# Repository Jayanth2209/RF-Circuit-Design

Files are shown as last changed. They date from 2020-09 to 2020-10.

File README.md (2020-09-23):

# RF Circuit Design
#### [Link to the Video](https://youtu.be/TnRn3Kn_aXg)         

### Five Rules: 
#### 1) Use 4 Layers:      
* Top (RF and Signals)          
* GND just below 1                 
* VCC above the bottom (15 on Eagle)           
* Bottom (Signals)             

* Use a consistent stack-up            
* Dedicate entire inner layers to unbroken power supply planes           
* Keep RF Signals on Top     

##### 4-Layer Board stackup:   
The 4 layer board stackup is as follows:      
* 1 mil solder resist      
* 1 oz Cu (1.4 mil)    
* 6.7 mil prepreg     
* 0.5 oz Cu (0.7 mil)   
* 47 mil Core     
* 0.5 oz Cu (0.7 mil)           
* 6.7 mil prepreg        
* 1 oz Cu (1.4 mil)         
* 1 mil solder resist         

[Setting up Multi-layer on Eagle](https://youtu.be/0sVUkjXbqrM)            

#### 2) Choose Integrated components:     
Try to choose and use the most integrated components - RF ICs, Baluns, Filters, etc.     
Examples of RF ICs - CC2650, CC1310, AT86RF215, nRF24L01P(+) ans so many more integrated RF ICs are available...        

#### 3) 50 Ohms everywhere:     
Try to match everything to 50 ohms. If a component is not 50 ohms I/O or whatever, convert it to 50 ohms.     
How? - Refer to it's Datasheet (Matching/Application Circuit)    

* Follow Manufacturer Recommendations (for matching)  -------------  **(4)**      

##### Note: For matching the RF traces on the Top layer of the circuit board to 50 Ohms, they have to be 12 mils wide (Considering the 4 layer board stackup specifications as mentioned above). So, on Eagle, Set - Trace width = 12 mils, Trace thickness = 1.4 mils             

After making your circuit, with all the above rules in mind:       
* Route RF first  --------------  **(5)**    
* Keep RF traces short and direct     
* Keep other signals away from RF (keep buffer zones next to RF traces, try to route other signals considerable away from RF signals)

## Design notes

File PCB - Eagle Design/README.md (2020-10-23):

# PCB        
A PCB has been designed on Eagle with the following components:           
[Reference Schematic]()          

* RF Transceiver:      
CC1121 - Texas Instruments        
[Datasheet - CC1121](https://www.ti.com/lit/ds/swrs111f/swrs111f.pdf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)       

* Antenna:     
ANT-916-CW-RCL-CCC      
[Antenna Datasheet]()       

* Other Components(Crystal Oscillator, Capacitors, Resistors and Inductors)       
[Components List]()      

* RF Module with Type-C USB Connector: Designed using Eagle       
[RF Module 1]()        
This module can be independently powered via a type-C USB connector or it can also be interfaced with an MCU(includes VCC, GND, GPIOs and pins corresponding to SPI Interfacing of the module)     

* RF Module without Type-C connector: Designed using Eagle      
[RF Module 2]()       
Only for interfacing with MCUs       
 
### PCB Design Guidelines:
Refer to these for important things to note while designing a PCB:     
[General guidelines for desiging an aesthetically pleasing PCB]()             
[RF PCB Design - A few things to note]()          

### Comparing the various types of Commercially available antennas:         

### Increasing the range of an RF-Module and theoretical Range estimations:           

### Calculating the range of the above designed PCB (CC1121 RF Transceiver):

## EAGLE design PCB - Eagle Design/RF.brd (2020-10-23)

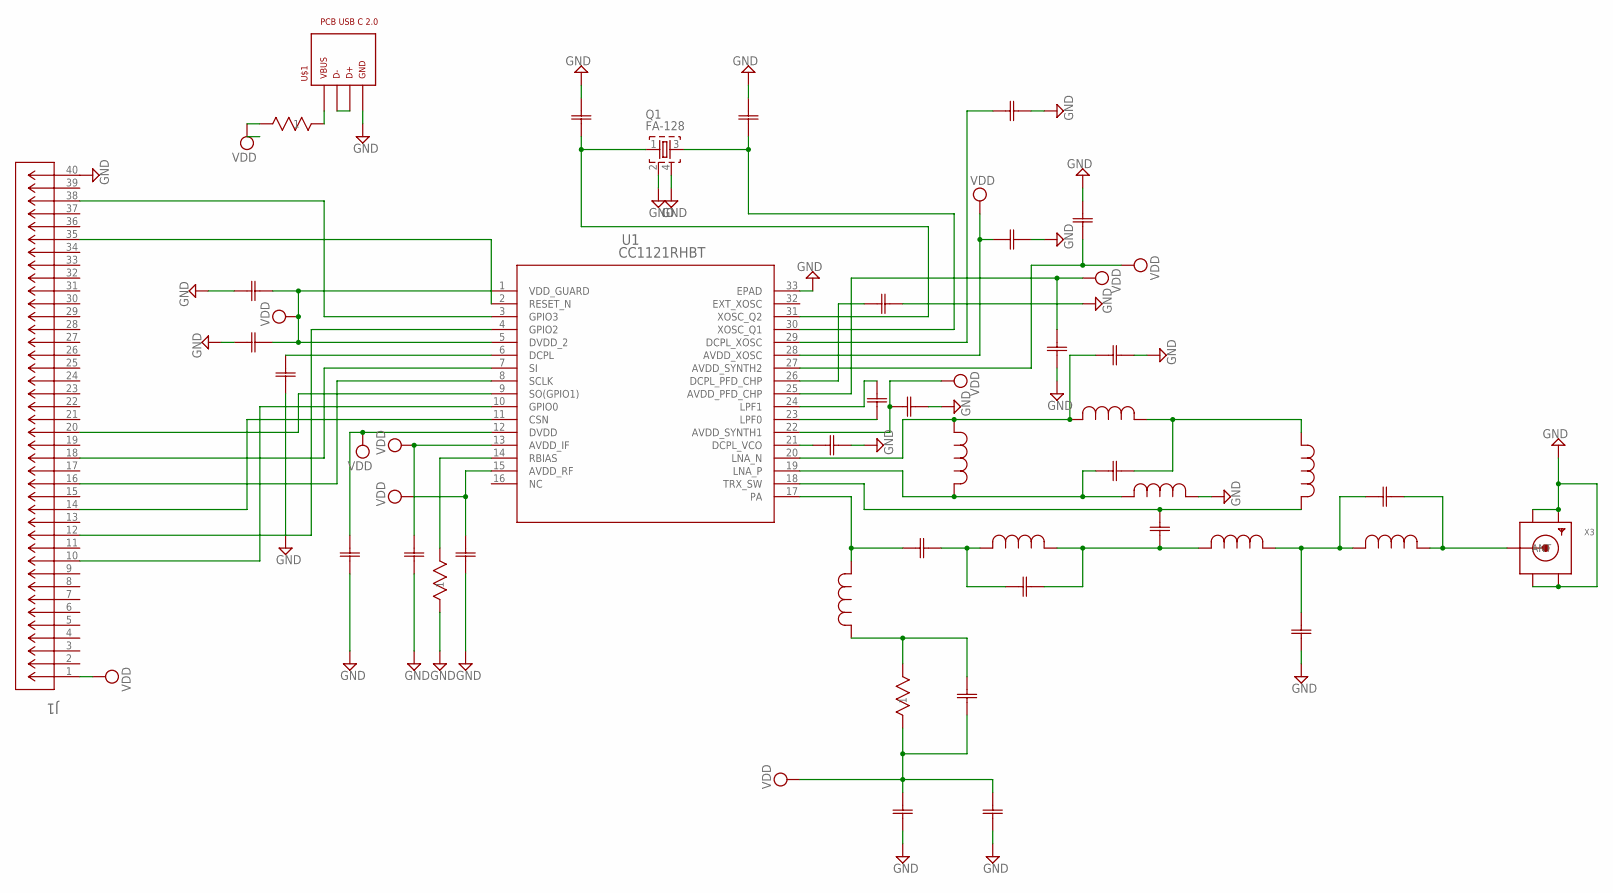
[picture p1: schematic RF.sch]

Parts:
C1, C9: 220nF; G-155_MUR
C2, C6, C7, C8, C20, C21, C22, C23, C26: 47nF; G-155_MUR
C3, C24, C25: 15pF; G-155_MUR
C4: 1pF; G-155_MUR
C5: 2.2pF; G-155_MUR
C10: 33pF; G-155_MUR
C11, C12: 10pF; G-155_MUR
C13: 3pF; G-155_MUR
C14: GRM155R71A104KA01D; G-155_MUR
C15, C16: 3.3pF; G-155_MUR
C17, C18: 10nF; G-155_MUR
C19: 1.8nF; G-155_MUR
J1: CLT-110-02-L-D-BE; CON20_2X10_DUME_CLT_SAI
L1, L2, L3: 10nH; IND_LQW15AN13NG00D_MUR
L4, L6, L7, L8: 12nH; IND_LQW15AN13NG00D_MUR
L5: 15nH; IND_LQW15AN13NG00D_MUR
Q1: FA-128
R1, R2, R3: 56k; RES_1E0402_1XP5_KOA
U1: CC1121RHBT; RHB32_3P45X3P45_TEX
U$1: PCB_USB_C_2.0DS_1; USB_TYPE_C_DS_1
X3: SMACONNECTOR_EDGE; SMA_EDGELAUNCH

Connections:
GND: C1.1, C2.1, C6.1, C7.1, C8.1, C9.1, C11.1, C12.1, C13.1, C16.2, C17.2, C18.2, C20.1, C21.2, C22.2, C23.2, C24.2, C25.2, C26.2, J1.40, L8.1, Q1.2, Q1.4, R1.1, U1.33 (EPAD), U$1.A1 (GND), U$1.A12 (GND), U$1.B1 (GND), U$1.B12 (GND), X3.GND@1 (GND4), X3.GND@2 (GND3), X3.GND@3 (GND2), X3.GND@4 (GND1)
unnamed: J1.35, U1.2 (RESET_N)
unnamed: J1.38, U1.3 (GPIO3)
unnamed: J1.12, U1.4 (GPIO2)
unnamed: C9.2, U1.6 (DCPL)
unnamed: J1.18, U1.7 (SI)
unnamed: J1.16, U1.8 (SCLK)
unnamed: J1.20, U1.9 (SO(GPIO1))
unnamed: J1.10, U1.10 (GPIO0)
unnamed: J1.14, U1.11 (CSN)
unnamed: R1.2, U1.14 (RBIAS)
unnamed: C3.1, L1.1, U1.17 (PA)
unnamed: C3.2, C4.1, L2.2
unnamed: C5.2, L7.1, U1.18 (TRX_SW)
unnamed: C4.2, C5.1, L2.1, L3.2
unnamed: C10.2, L1.2, R2.2
unnamed: C15.2, L6.1, L7.2
unnamed: C13.2, C14.1, L3.1, L4.2
unnamed: C17.1, U1.21 (DCPL_VCO)
unnamed: C14.2, L4.1, X3.P (ANT)
unnamed: C15.1, L5.1, L8.2, U1.19 (LNA_P)
unnamed: C16.1, L5.2, L6.2, U1.20 (LNA_N)
unnamed: C19.1, U1.23 (LPF0)
unnamed: C19.2, U1.24 (LPF1)
unnamed: C26.1, U1.29 (DCPL_XOSC)
unnamed: C21.1, U1.26 (DCPL_PFD_CHP)
unnamed: C25.1, Q1.3, U1.30 (XOSC_Q1)
unnamed: C24.1, Q1.1, U1.31 (XOSC_Q2)
unnamed: R3.1, U$1.A4 (VBUS), U$1.A9 (VBUS), U$1.B4 (VBUS), U$1.B9 (VBUS)
unnamed: U$1.A6 (D+), U$1.A7 (D-), U$1.B6 (D+), U$1.B7 (D-)
VDD: C1.2, C2.2, C6.2, C7.2, C8.2, C10.1, C11.2, C12.2, C18.1, C20.2, C22.1, C23.1, J1.1, R2.1, R3.2, U1.1 (VDD_GUARD), U1.5 (DVDD_2), U1.12 (DVDD), U1.13 (AVDD_IF), U1.15 (AVDD_RF), U1.22 (AVDD_SYNTH1), U1.25 (AVDD_PFD_CHP), U1.27 (AVDD_SYNTH2), U1.28 (AVDD_XOSC)

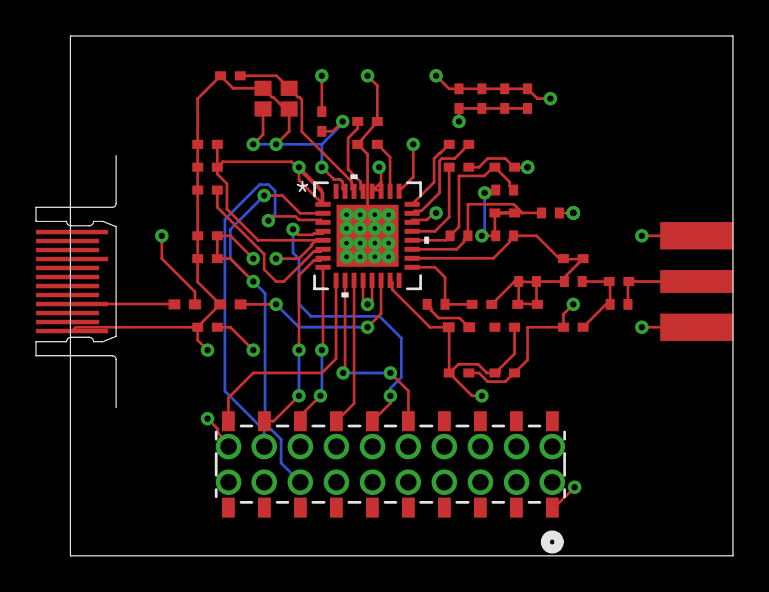
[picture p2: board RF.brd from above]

Board: 4 copper layers, 38.7 x 28.9 mm, 42 parts (0 on the bottom side), 31 nets.

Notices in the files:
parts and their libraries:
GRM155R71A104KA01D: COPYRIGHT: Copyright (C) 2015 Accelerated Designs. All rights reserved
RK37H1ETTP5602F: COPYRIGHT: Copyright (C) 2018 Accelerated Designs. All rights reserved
